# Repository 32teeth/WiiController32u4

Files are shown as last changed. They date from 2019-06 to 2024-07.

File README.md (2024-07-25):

# WiiController32u4

`WiiController32u4` is an Arduino project that allows you to use a Wii Classic Controller as an input device for your Arduino-based projects. The code reads the button states of the Wii Classic Controller and processes them to be used in various applications.

| Top | Bottom |
|--|--|
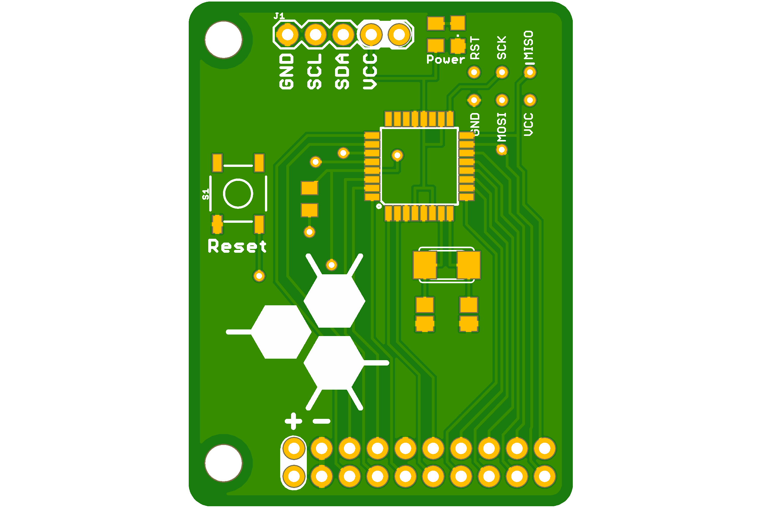
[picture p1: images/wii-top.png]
Top
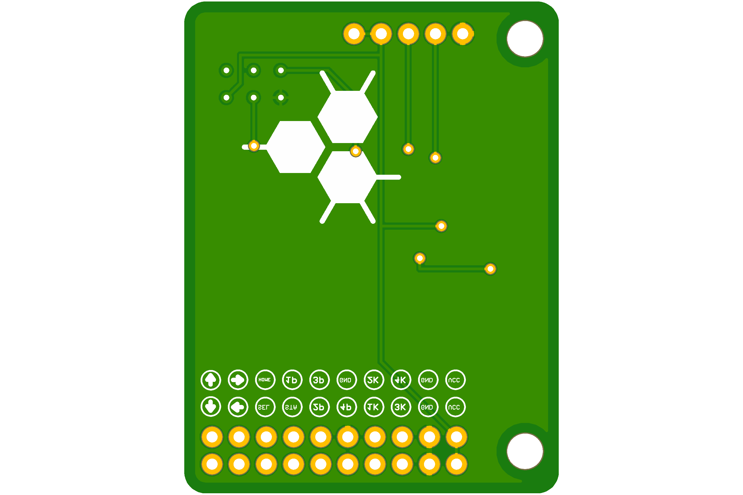
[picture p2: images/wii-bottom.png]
Bottom
|  |  |

## Features

- Supports all buttons on the Wii Classic Controller
- Reads and processes analog stick positions
- Configurable pin mappings for the buttons
- Simple integration with other Arduino projects

## Hardware Requirements

- Arduino board (e.g., Arduino Leonardo)
- Wii Classic Controller
- Necessary wiring to connect the Wii Classic Controller to the Arduino

## Software Requirements

- [Arduino IDE](https://www.arduino.cc/en/software)
- [Wire Library](https://www.arduino.cc/en/Reference/Wire) (included with Arduino IDE)

## Pin Configuration

The following table shows the pin configuration for the Wii Classic Controller buttons:

| Button | Arduino Pin |
|---|---|
| D-PAD LEFT | A3 |
| D-PAD RIGHT  | A2 |
| D-PAD UP | A4 |
| D-PAD DOWN | A5 |
| A BUTTON | 4 |
| B BUTTON | 6 |
| X BUTTON | 10 |
| Y BUTTON | 13 |
| L BUTTON | 9 |
| R BUTTON | 12 |
| MINUS BUTTON | A0 |
| PLUS BUTTON  | 5 |
| HOME BUTTON  | A1 |
| ZL BUTTON | 8 |
| ZR BUTTON | 2 |

## Usage

1. Clone or download the repository to your local machine.
2. Open the `wcc.ino` file in the Arduino IDE.
3. Connect the Wii Classic Controller to your Arduino board as per the pin configuration.
4. Upload the code to your Arduino board.

## License

This project is licensed under the MIT License - see the [LICENSE](LICENSE) file for details.

## Contributing

Contributions are welcome! Please open an issue or submit a pull request for any changes

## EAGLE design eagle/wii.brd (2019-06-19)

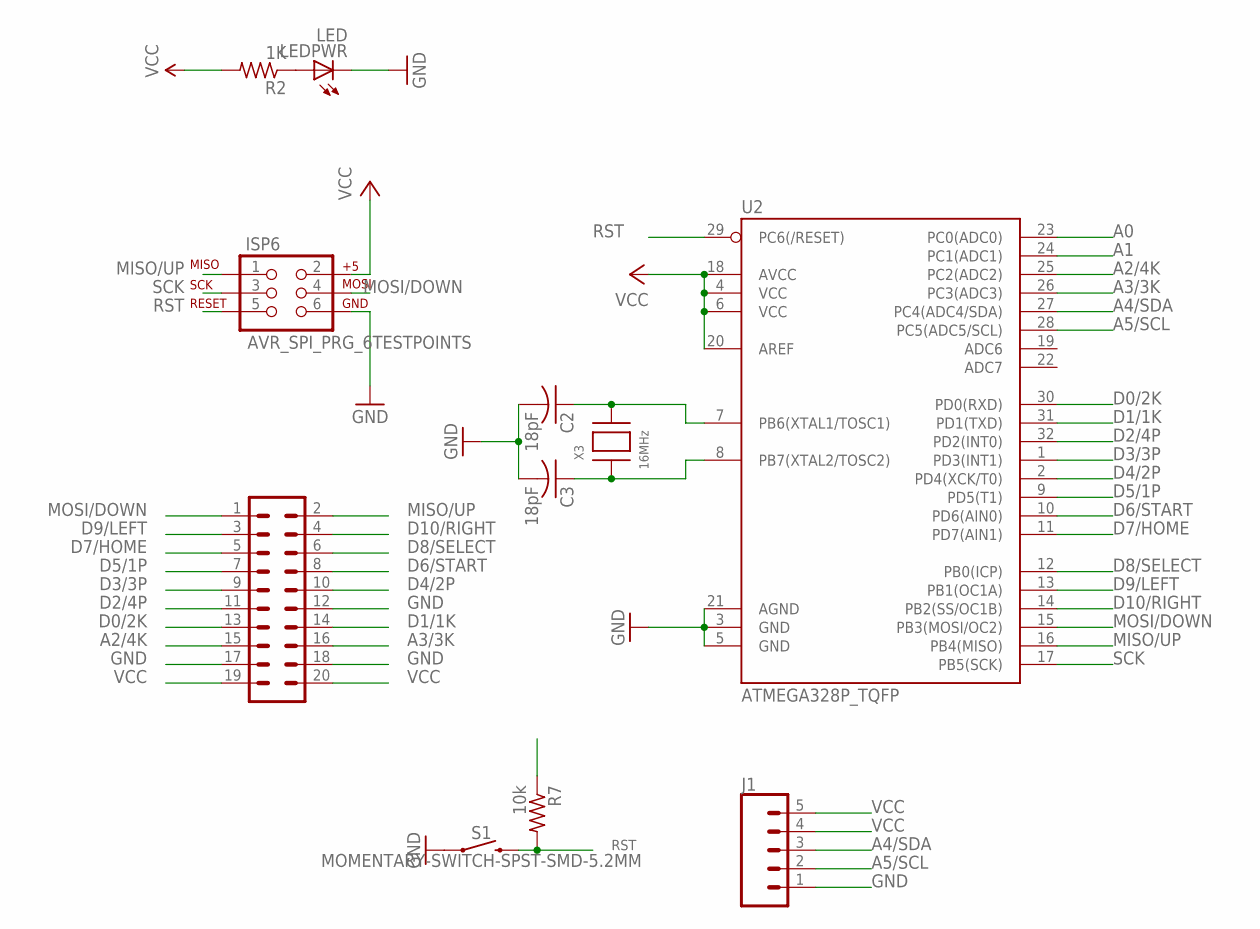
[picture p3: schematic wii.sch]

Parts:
C2, C3: 18pF; C0805
ISP6: AVR_SPI_PRG_6TESTPOINTS; 2X3_TEST_POINTS
J1: CONN_05; 1X05
LEDPWR: LED; CHIPLED_0805
R2: 1K; R0805
R7: 10k; R0805
S1: MOMENTARY-SWITCH-SPST-SMD-5.2MM; TACTILE_SWITCH_SMD_5.2MM
U2: ATMEGA328P_TQFP; TQFP32-08
U$1: 20 pin breakout; 2X10_ROUND_NOSILK
X3: 16MHz; NX5032

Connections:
A0: U2.23 (PC0(ADC0))
A1: U2.24 (PC1(ADC1))
A2/4K: U2.25 (PC2(ADC2)), U$1.15
A3/3K: U2.26 (PC3(ADC3)), U$1.16
A4/SDA: J1.3, U2.27 (PC4(ADC4/SDA))
A5/SCL: J1.2, U2.28 (PC5(ADC5/SCL))
D0/2K: U2.30 (PD0(RXD)), U$1.13
D1/1K: U2.31 (PD1(TXD)), U$1.14
D2/4P: U2.32 (PD2(INT0)), U$1.11
D3/3P: U2.1 (PD3(INT1)), U$1.9
D4/2P: U2.2 (PD4(XCK/T0)), U$1.10
D5/1P: U2.9 (PD5(T1)), U$1.7
D6/START: U2.10 (PD6(AIN0)), U$1.8
D7/HOME: U2.11 (PD7(AIN1)), U$1.5
D8/SELECT: U2.12 (PB0(ICP)), U$1.6
D9/LEFT: U2.13 (PB1(OC1A)), U$1.3
D10/RIGHT: U2.14 (PB2(SS/OC1B)), U$1.4
GND: C2.2, C3.2, ISP6.6, J1.1, LEDPWR.C, S1.1, U2.3 (GND), U2.5 (GND), U2.21 (AGND), U$1.12, U$1.17, U$1.18
MISO/UP: ISP6.1, U2.16 (PB4(MISO)), U$1.2
MOSI/DOWN: ISP6.4, U2.15 (PB3(MOSI/OC2)), U$1.1
unnamed: LEDPWR.A, R2.1
unnamed: C2.1, U2.7 (PB6(XTAL1/TOSC1)), X3.P$2
unnamed: C3.1, U2.8 (PB7(XTAL2/TOSC2)), X3.P$1
RST: ISP6.5, R7.2, S1.3 (2), U2.29 (PC6(/RESET))
SCK: ISP6.3, U2.17 (PB5(SCK))
VCC: ISP6.2, J1.4, J1.5, R2.2, R7.1, U2.4 (VCC), U2.6 (VCC), U2.18 (AVCC), U2.20 (AREF), U$1.19, U$1.20

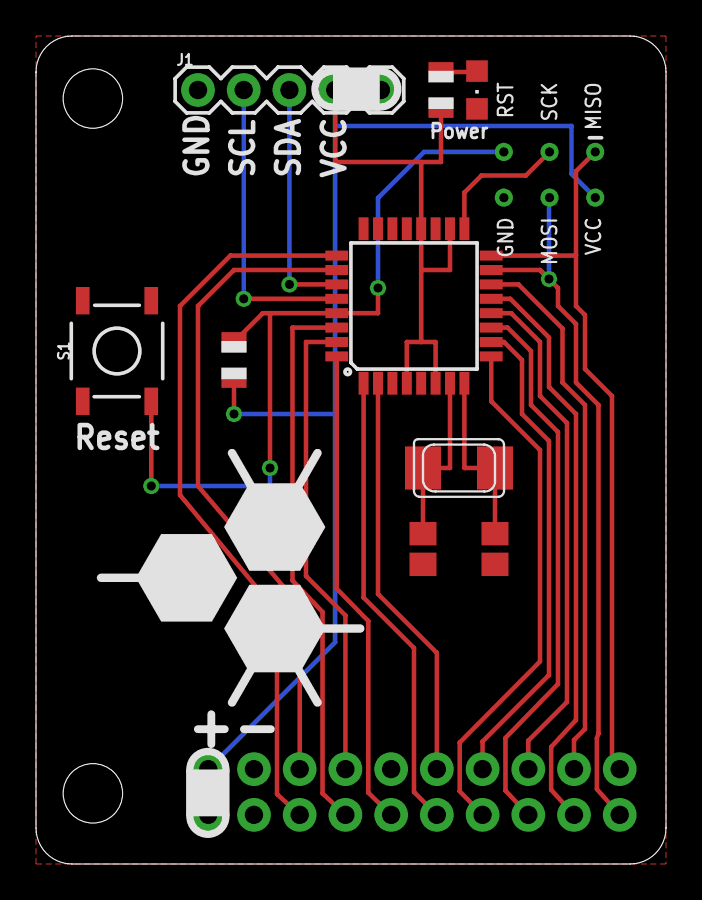
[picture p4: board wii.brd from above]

Board: 2 copper layers, 35.0 x 46.0 mm, 13 parts (1 on the bottom side), 24 nets.

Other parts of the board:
U$2, U$3: STAND-OFF

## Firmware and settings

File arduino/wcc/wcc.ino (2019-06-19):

#include "Wire.h" // This seems redundant, but we need to declare this
                  // dependency in the pde file or else it won't be included
                  // in the build.

#include "wiimote.h"

// Classic Controller Buttons
int BDL = 0; // D-PAD LEFT STATE
int BDR = 0; // D-PAD RIGHT STATE
int BDU = 0; // D-PAD UP STATE
int BDD = 0; // D-PAD DOWN STATE
int BA = 0; // A BUTTON STATE
int BB = 0; // B BUTTON STATE
int BX = 0; // X BUTTON STATE
int BY = 0; // Y BUTTON STATE
int BL = 0; // L BUTTON STATE
int BR = 0; // R BUTTON STATE
int BM = 0; // MINUS BUTTON STATE
int BP = 0; // PLUS BUTTON STATE
int BHOME = 0; // HOME BUTTON STATE
int BZL = 0; // ZL BUTTON STATE
int BZR = 0; // ZR BUTTON STATE


const int PIN_BY = 13;				// P1
const int PIN_BL = 9;				// P2
const int PIN_BX = 10;				// P3
const int PIN_BZL = 8;				// P4

const int PIN_BB = 6;				// K1
const int PIN_BR = 12;				// K2
const int PIN_BA = 4;				// K3
const int PIN_BZR = 2;				// K4

const int PIN_BP = 5;				// START
const int PIN_BM = A0;			// SELECT
const int PIN_BHOME = A1;		// HOME

const int PIN_BDR = A2;			// RIGHT
const int PIN_BDD = A5;			// DOWN
const int PIN_BDL = A3;			// LEFT
const int PIN_BDU = A4;			// UP

const int BUTTONS[15] = {BDL,BDR,BDU,BDD,BA,BB,BX,BY,BL,BR,BM,BP,BHOME,BZL,BZR};


/*
 * Analog Buttons.
 * They are initialized with center values from the calibration buffer.
 */
byte LX = calbuf[2]>>2;
byte LY = calbuf[5]>>2;
byte RX = calbuf[8]>>3;
byte RY = calbuf[11]>>3;


// Wiimote button data stream
byte *stream_callback(byte *buffer) {
	wiimote_write_buffer(buffer, BDL, BDR, BDU, BDD, BA, BB, BX, BY, BL, BR, BM, BP, BHOME, LX, LY, RX, RY, BZL, BZR);
	return buffer;
}

void setup() {
	// Set PushButton pins as input, turning pull-up on
	for(int i = 0; i < 15; i++)
	{
		pinMode(BUTTONS[i], INPUT);
		digitalWrite(BUTTONS[i], HIGH);
	}

	// Prepare wiimote communications
	wiimote_stream = stream_callback;
	wiimote_init();
}

void loop() {
	BDL = digitalRead(PIN_BDL);
	BDR = digitalRead(PIN_BDR);
	BDU = digitalRead(PIN_BDU);
	BDD = digitalRead(PIN_BDD);
	BA = digitalRead(PIN_BA);
	BB = digitalRead(PIN_BB);
	BX = digitalRead(PIN_BX);
	BY = digitalRead(PIN_BY);
	BL = digitalRead(PIN_BL);
	BR = digitalRead(PIN_BR);
	BM = digitalRead(PIN_BM);
	BP = digitalRead(PIN_BP);
	BHOME = digitalRead(PIN_BHOME);
	BZL = digitalRead(PIN_BZL);
	BZR = digitalRead(PIN_BZR);

	delay(50);
}

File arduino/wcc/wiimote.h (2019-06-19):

/*
 * Copyright (c) 2011 Peter Brinkmann (peter.brinkmann@gmail.com)
 *
 * For information on usage and redistribution, and for a DISCLAIMER OF ALL
 * WARRANTIES, see the file, "LICENSE.txt," in this distribution.
 *
 * Bare-bones Nintendo Wiimote library for Arduino, tricking the Wiimote into
 * treating the Arduino as a Classic Controller.  Communication works both to and from
 * the Arduino.
 *
 * Using insights into the communication between Wiimote and Nunchuk found
 * at http://www.ccsinfo.com/forum/viewtopic.php?p=91094.  The wmgui tool that
 * comes with cwiid is good for experimenting and testing.
 *
 * Here's how to connect the Arduino to the Wiimote:
 *      Arduino    Wiimote
 *      GND        GND  (white cable)
 *      AREF       3.3V (red cable)
 *      A4         SDA  (green cable)
 *      A5         SCL  (yellow cable)
 *
 * It doesn't look like it's possible to power the Arduino from the Wiimote.
 *
 * Note that some online instructions for using a Wiimote extension
 * with Arduino call for changes to twi.h.
 * Fortunately, this modification is no longer
 * necessary.  Just use a current version of the Arduino development
 * environment.
 */

#ifndef __WIIMOTE_H__
#define __WIIMOTE_H__

#if defined(ARDUINO) && ARDUINO >= 100
  #include "Arduino.h"
  #else
  #include "WProgram.h"
  #endif
#include "Wire.h"
#include "wm_crypto.h"

// Identification sequence for Classic Controller
static byte idbuf[] = { 0x00, 0x00, 0xa4, 0x20, 0x01, 0x01 };

// Classic Controller calibration data
byte calbuf[] = { 0xFC, 0x04, 0x7E, 0xFC, 0x04, 0x7E, 0xFC, 0x04, 0x7E,
		0xFC, 0x04, 0x7E, 0x00, 0x00, 0x00, 0x00 }; // Checksum will be calculated later...

//byte calbuf[] = { 0xff, 0x00, 0x80, 0xff, 0x00, 0x80, 0xff, 0x00, 0x80, 0xff,
//		0x00, 0x80, 0x00, 0x00, 0x51, 0xa6 }; // Homebrews (libogc) don't seem to like this one...

static byte outbuf[6];
static byte *curbuf = outbuf;
static byte state = 0;
static byte crypt_setup_done = 0;

/*
 * This function pointer informs the Arduino that a byte has been
 * written to one of the registers corresponding to the Extension.
 * Specifically, if you assign the function foo to this pointer and
 * you write yy bytes starting at the register address 04a400xx of
 * the Wiimote, then this library will call foo(xx, yy).  The bytes
 * are written to the global array wiimote_registers.
 *
 * Note that count will always be less than eight.  If you write
 * eight or more bytes to the Wiimote, this callback will be
 * invoked several times.
 */
void (*wiimote_receive)(byte offset, byte count) = NULL;

/*
 * Callback for streaming bytes from the Arduino to the Wiimote.
 * If this function pointer is not null, then it will be called
 * right _after_ the current output buffer has been sent to the
 * Wiimote, and the implementing function has the choice of either
 * overwriting the given buffer and returning it or returning
 * another buffer that contains the next six bytes to be sent.
 *
 * The return value of this function becomes the new output buffer.
 * The idea is much like the one behind wiimote_swap_buffers.  You
 * probably want to use only one of them; either wiimote_stream
 * for streaming data, or wiimote_swap_buffers for more sporadic
 * updates.
 *
 * There is one exception to this rule: Since this function is
 * called after the current output buffer has been sent, the very
 * first buffer will be all zero unless you initialize it with
 * wiimote_set_byte or wiimote_swap_buffers.  (This approach may
 * seem awkward, but it minimizes delays in I2C communication, and
 * in most cases an all-zero initial buffer is not a problem.)
 */
byte *(*wiimote_stream)(byte *buffer) = NULL;

/*
 * Global array for storing and accessing register values written
 * by the Wiimote.  Those are the 256 registers corresponding to
 * the Extension, starting at 04a40000.
 */
byte wiimote_registers[0x100];

/*
 * Start Wiimote <-> Extension communication encryption,
 * if requested by the application.
 */

static void setup_encryption() {
	int i;

	for (i = 0x40; i <= 0x49; i++) {
		wm_rand[9 - (i - 0x40)] = wiimote_registers[i];
	}

	for (i = 0x4A; i <= 0x4F; i++) {
		wm_key[5 - (i - 0x4A)] = wiimote_registers[i];
	}

	wm_gentabs();

	crypt_setup_done = 1;
}

/*
 * Generic function for sending data via Wire.write().
 * Supports Wiimote encryption, if enabled.
 */
static void send_data(uint8_t* data, uint8_t size, uint8_t addr) {
	static uint8_t buffer[8];
	int i;

	if (wiimote_registers[0xF0] == 0xAA && crypt_setup_done) {
		for (i = 0; i < size; i++) {
			buffer[i] = (data[i] - wm_ft[(addr + i) % 8]) ^ wm_sb[(addr + i)
					% 8];
		}

		Wire.write(buffer, size);
	} else {
		Wire.write(data, size);
	}
}

static void receive_bytes(int count) {
	byte crypt_keys_received = 0;

	if (count == 1) {
		state = Wire.read();
	} else if (count > 1) {
		byte addr = Wire.read();
		byte curr = addr;

		for (int i = 1; i < count; i++) {
			byte d = Wire.read();

			// Wii is trying to disable encryption...
			if(addr == 0xF0 && d == 0x55) {
				crypt_setup_done = 0;
			}

			if (wiimote_registers[0xF0] == 0xAA && crypt_setup_done) {
				// Decrypt
				wiimote_registers[curr] = (d ^ wm_sb[curr % 8]) + wm_ft[curr
						% 8];
				curr++;
			} else {
				wiimote_registers[curr++] = d;
			}

			// Check if last crypt key setup byte was received...
			if (curr == 0x50) {
				crypt_keys_received = 1;
			}

		}
		if (wiimote_receive) {
			wiimote_receive(addr, (byte) count - 1);
		}
	}

	// Setup encryption
	if (crypt_keys_received) {
		setup_encryption();
	}

}

static void handle_request() {

	static byte last_state = 0xFF;
	static byte offset = 0;

	switch (state) {

	case 0x00:
		send_data(curbuf, 6, 0x00);

		if (wiimote_stream) {
			curbuf = wiimote_stream(curbuf);
		}

		break;

	case 0xFA:
		send_data(wiimote_registers + state, 6, state);

		break;

	default:
		if(last_state == state) {
			offset += 8;
		} else {
			last_state = state;
			offset = 0;
		}

		send_data(wiimote_registers + state + offset, 8, state + offset);
		break;
	}
}

/*
 * Sets the given value of the current buffer.
 *
 * index of the value to be set, 0 <= index < 6
 * value new value of the byte at the given index
 *
 * Make sure to read the documentation of wiimote_stream if you
 * intend to use both wiimote_stream and this function.
 */
void wiimote_set_byte(int index, byte value) {
	curbuf[index] = value;
}

/*
 * Makes the given buffer the current buffer and returns the
 * previous buffer.  Use this function if you want to change
 * several values at once.
 *
 * buffer must be a byte buffer of length at least 6.
 *
 * Returns the previous buffer, suitable for reuse.
 *
 * Make sure to read the documentation of wiimote_stream if you
 * intend to use both wiimote_stream and this function.
 */
byte *wiimote_swap_buffers(byte *buffer) {
	byte *tmp = curbuf;
	curbuf = buffer;
	return tmp;
}
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

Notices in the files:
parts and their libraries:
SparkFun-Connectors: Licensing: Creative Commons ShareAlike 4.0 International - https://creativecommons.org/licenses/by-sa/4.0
